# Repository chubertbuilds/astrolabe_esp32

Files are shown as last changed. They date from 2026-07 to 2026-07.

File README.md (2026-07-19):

<h1 align=center>
  Astrolabe
</h1>
<h3 align=center>
  An ESP32-S3 implementation of the historical scientific instrument
</h3>

<p align=center>
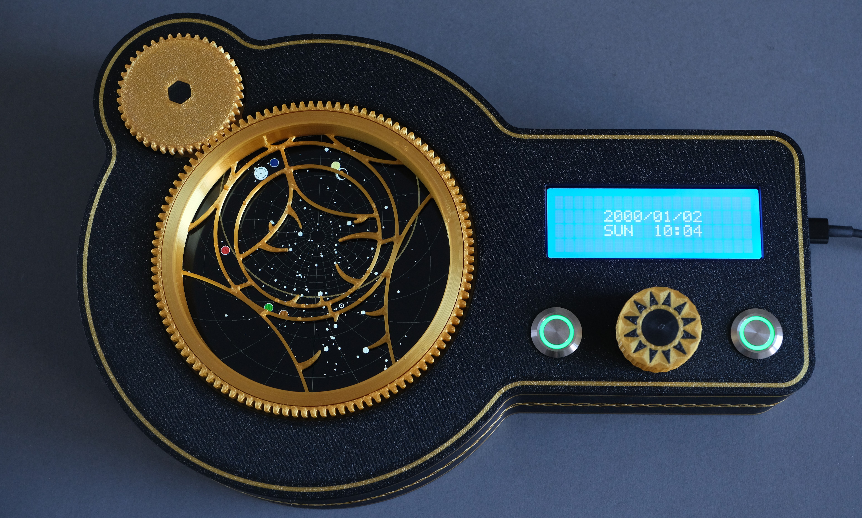
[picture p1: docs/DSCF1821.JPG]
  
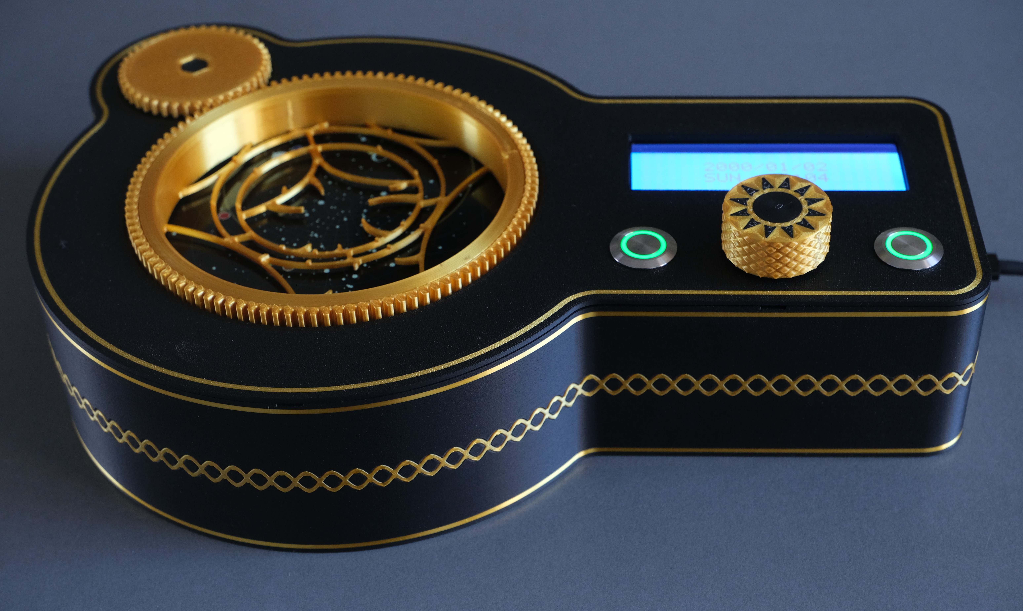
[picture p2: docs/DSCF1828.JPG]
   
</p>

## Licensing
The hardware and software designs in this repository are licensed separately:

* **Software:** The .ino sketch in the root folder and all files in "src" are licensed under the [MIT License](LICENSE).
* **Hardware:** The CAD files in "hardware" are all licensed under the [CERN-OHL-S License](LICENSE-HW).

## Introduction
An [astrolabe](https://en.wikipedia.org/wiki/Astrolabe) is a historical scientific instrument which was used to tell the time, map the sky, and find directions—among, it is obligatory to say, many other applications.

This project provides the hardware and software files to build a modern, microcontroller-driven version of the astrolabe. Given a user-inputted date, time, and location, it maps the fixed stars and seven classical planets on a 4''x4'' LCD panel. A secondary 20x4 character LCD screen displays detailed information about the sky.

Alex Boxer's [online astrolabe](https://alexboxer.com/astrolabe/) provided the inspiration for this project. If you're curious about these beautiful devices, I highly recommend you explore Boxer's astrolabe to learn more.

## Components

I used the following components in this build:

| Component  | Quantity
| --- | --- |
|[Qualia ESP32-S3 Dev Board](https://www.adafruit.com/product/5800)| 1
|[4'' 720 x 720 Display](https://www.adafruit.com/product/5793)| 1
|[i2c LCD Backpack](https://www.adafruit.com/product/292)| 1
|[20x4 Character Display](https://www.adafruit.com/product/198)| 1
|[Rotary Encoder Breakout w/ Encoder](https://www.adafruit.com/product/5880)| 1
|[PCF8574 I2C Breakout](https://www.adafruit.com/product/5545)| 1
|[16mm RGB Momentary Button](https://www.adafruit.com/product/3350)| 2
|[200mm JST SH 4-Pin Cables](https://www.adafruit.com/product/4401)| 3
|[40-pin FPC Extension](https://www.adafruit.com/product/2098)| 1
|3-pin JST PH Cable male connector w/ pigtails | 1 |
|Pair of 2-pin JST male-female connectors w/ pigtails | 1 |
| Pair of 6-pin JST male-female connectors w/ pigtails | 2|
| [10-turn 1K ohm Potentiometer](https://www.amazon.com/Taiss-Precision-Potentiometer-Adjustable-3590S-2-103L/dp/B07D7YH9N2/) | 1 |
| 110 ohm trimmer resistor | 1 |
| [#4 1/4'' Thread-Forming Phillips Screws](https://www.mcmaster.com/90417A116/) | 50
| [5/16'' Ø Delrin Balls](https://www.mcmaster.com/products/9614k57/) | 12
| [0.06'' Ø 1/8'' Thick Neodymium Magnets](https://www.mcmaster.com/catalog/5862K11) | 16
| [4-40 1/4'' Set Screws](https://www.mcmaster.com/products/92311a106/) | 4
| 110 Ohm, 0.25 W Resistor | 1

Where possible, I'm linking to the exact component I purchased. Substitutions can be made as needed.

## 3D Printing

The twelve 3D-printed parts used in this project are all listed in the [hardware](hardware) folder. All of these parts must be printed once, except for Astrolabe_BearingCage, which must be printed twice.

I printed all these parts with a Bambu P1S printer, using a combination of matte black and silk gold PLA filament. Given that my setup will likely differ substantially from yours, I haven't provided .3mf files (also, to tell the truth, I didn't do a great job of record-keeping with my print files).

Some 3D printing pointers:

- Some parts need to be printed with their counterbores upside down. For these parts, there are features on the counterbores which force the slicer to use bridges, eliminating the need for supports.
- While some parts can be printed in orientations that eliminate supports, those orientations may not be ideal. For example, the encoder knob can be printed with the knob face on the print bed; this orientation doesn't need supports, but it makes the knob less shiny.
- When printing with silk gold PLA, I recommend lowering speeds to <50 mm/s for the outer walls and the top layer.
- When printing with supports, I recommend using a PLA-incompatible material, such as PETG or the proprietary Bambu "Support for PLA/PETG," for the support interface.

Finally, several parts interface with tight clearance fits. Depending on your setup, you may need to modify dimensions to get a good fit. If you need to do so, or you want to make any other change to the design, you can access .STEP files [here.](hardware/step/)

## Build Instructions

### Tools
This build uses the following tools and consumables:

- A #1 phillips head screwdriver
- A 0.05'' Allen wrench
- A soldering station
- Epoxy glue 
- Nylon tape
- A 4-40 tap

### Soldering
Before beginning assembly, all the soldering work should be complete. The soldering work is comprised of the following tasks:

  1. Solder the character display backpack to the character display. Note: the screw terminal on the backpack needs to be removed, as it doesn't fit in the build. This can be done via a skillful, dextrous desoldering job, or you can use a pair of pliers to rip the screw terminal off the PCB. Guess which path I took.
  2. Solder the 3-pin JST PH cable to the prongs of the potentiometer. On the Qualia's 3-pin JST connector, the left pin is signal, the middle pin is power, and the right pin is ground. Connect signal to potentiometer pin 2, power to potentiometer pin 1, and ground to potentiometer pin 3.
  3. Cut the power wire and splice the 110 Ohm resistor into it. The ESP32-S3 onboard ADC has a completely flat response at the top of its voltage input range, so we need the resistor to adjust the input signal.
  4. Solder one half of the 2-pin JST connector pair to the Qualia board. Solder one wire to MOSI and the other to MISO. We are repurposing these extra GPIO pins for interrupt signals.
  5. Solder the other half of the 2-pin connector pair to the interrupt pins of the encoder breakout and the GPIO expander. Connect MOSI to the encoder interrupt pin and MISO to the expander interrupt pin.
  6. For both buttons, solder one half of a 6-pin JST connector to the button. Each button comes with six prongs: an anode, two button contacts, and three LED cathodes.
  7. Solder the other half of the two 6-pin connectors to the GPIO expander. For the button-expander connections, solder the anode to power, the three LED cathodes to GPIO pins, one of the button contacts to ground, and the other button contact to a GPIO pin. All eight of the GPIO expander's pins should be occupied. The existing code uses the following pin assignments: 

      ~~~
      #define RIGHT_BLUE 0 
      #define RIGHT_GREEN 1 
      #define RIGHT_RED 2 
      #define RIGHT_BUTTON 3 
      #define LEFT_BLUE 4 
      #define LEFT_GREEN 5 
      #define LEFT_RED 6 
      #define LEFT_BUTTON 7 
      ~~~

### Bearing Cage Magnet Insertion

Before assembly, we also need to insert and glue magnets into the two bearing cage halves.

It's important to keep all the magnetic poles aligned—one of the cage halves must have all its magnets mounted with the north pole facing out, and one of them must have all the magnets with the south pole facing out.

To cleanly insert and glue the magnets:

1. Create a reservoir of epoxy.
2. Use a flathead screwdriver to pick up the magnet. The side that will face out should be contacting the tool.
3. Dip the other end of the magnet in the epoxy reservoir.
4. Use the screwdriver to press the magnet into the cage bore. 
5. Once the magnet has been fully inserted, slide the screwdriver off to break contact with the magnet. This breaks contact without pulling the magnet back out of the bore.
6. Let the cage sit for your epoxy's cure time.

### Tapping the Axle

The potentiometer axle uses four set screws to couple it to the potentiometer shaft. To insert these set screws into the axle, the four through holes in the axle must be tapped with a 4-40 tap.

To be sure, it is absolutely not best practice to directly tap a 3D-printed part, given that the resulting threads are quite weak. That said, they are strong enough for our application.

### Assembly

After printing, soldering, gluing, and tapping, it's time to build!

1. Gather all the 3D-printed parts and components on a large, clear workspace.

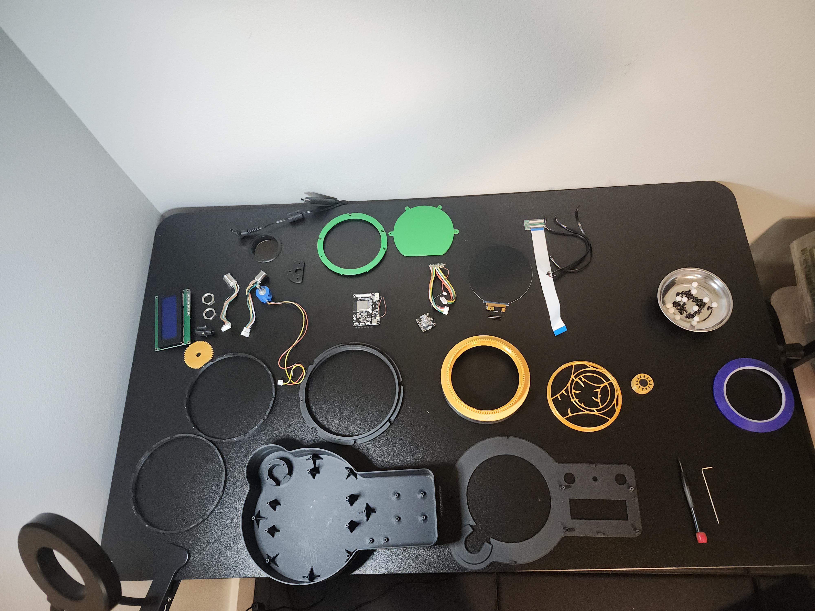
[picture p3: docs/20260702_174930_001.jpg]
    

2. Assemble the bearing. 
    - Arrange the inner bearing inside the outer bearing eccentrically, such that the outside of the inner bearing is making contact with the inside of the outer bearing at one point.
    - This will create a large gap on the opposite side of the contact point, through which the nylon balls can be inserted. Insert all twelve.

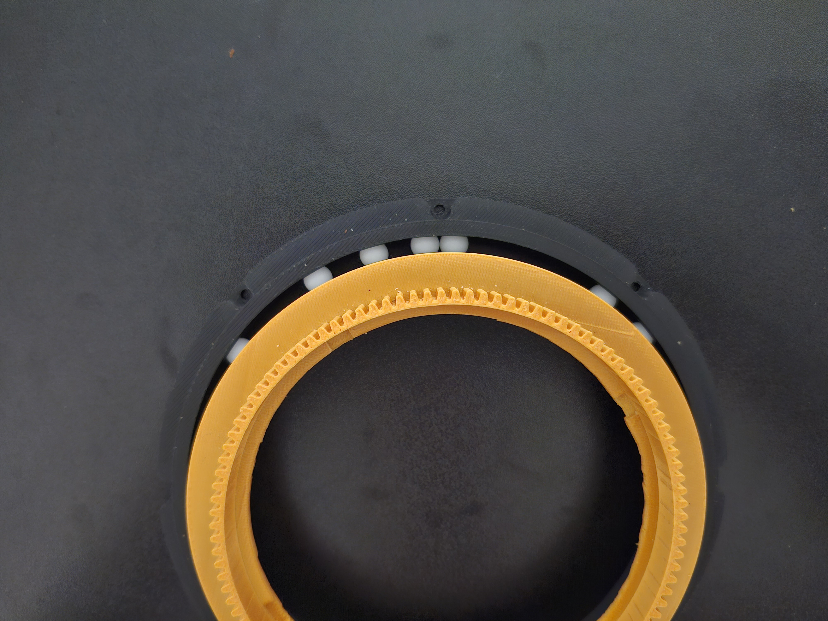
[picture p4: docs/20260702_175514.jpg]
        

    - As the balls are inserted, arrange them in a roughly even spacing. This will cause the inner and outer bearing to become concentric.
    - Take one half of the bearing cage and place it under the balls. The balls will not be inside their pockets, so the cage will not be fully seated.
    - Using a long tool such as a screwdriver, push the balls along the track until each ball is over a pocket. Once this happens, the assembly will fall into place over the bearing cage.

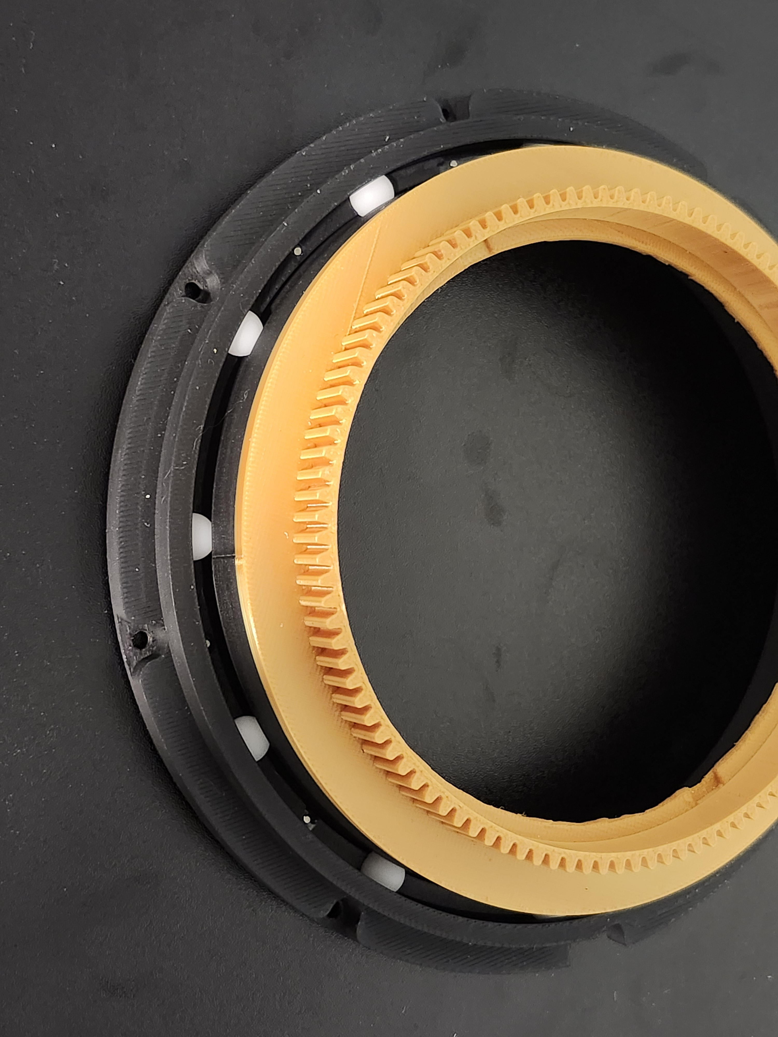
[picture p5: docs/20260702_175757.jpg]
        

    - Place the other half of the bearing cage over the assembly; the magnets will lock it into place.

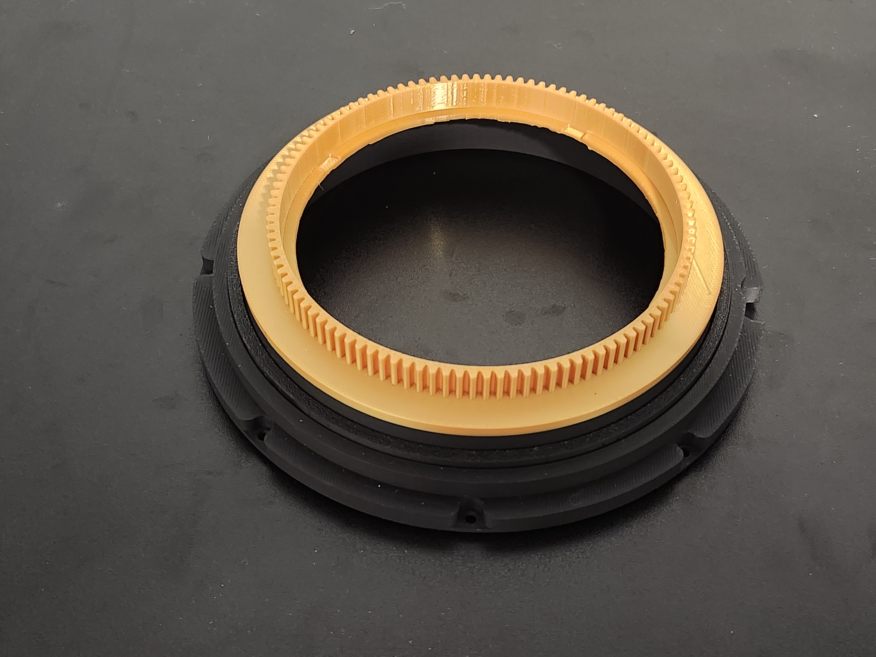
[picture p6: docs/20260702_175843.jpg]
        

    - Spin the bearing around like a fidget toy.
3. Assemble the display enclosure.
    - Insert the display inside the display mount, facing out.

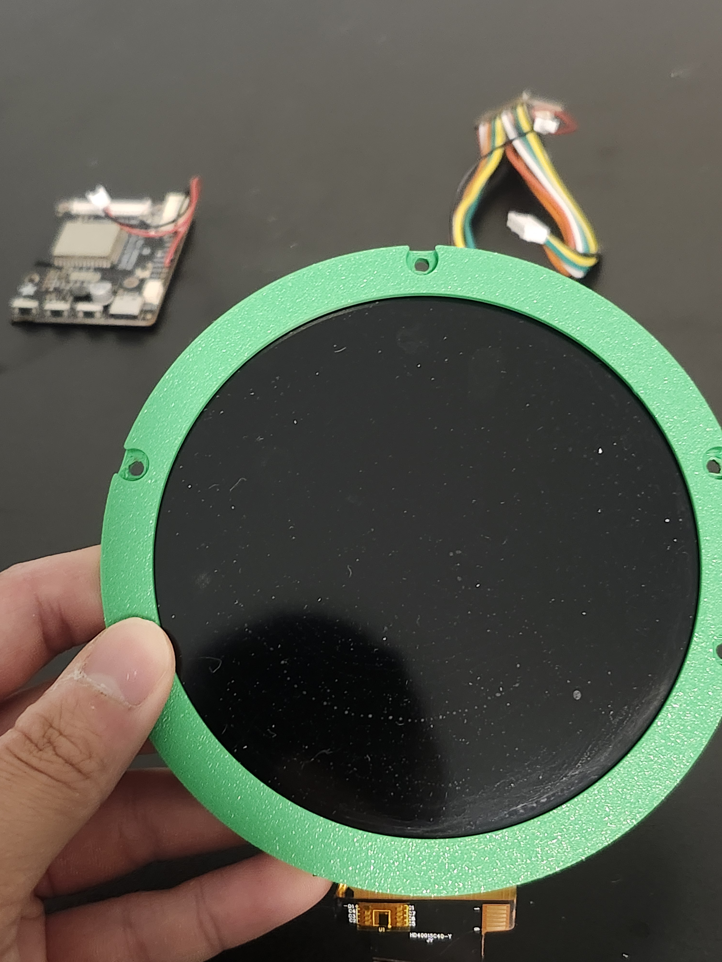
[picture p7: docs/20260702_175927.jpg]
        

    - Fit the display base on the other side of the display mount, sandwiching the display between the two parts.

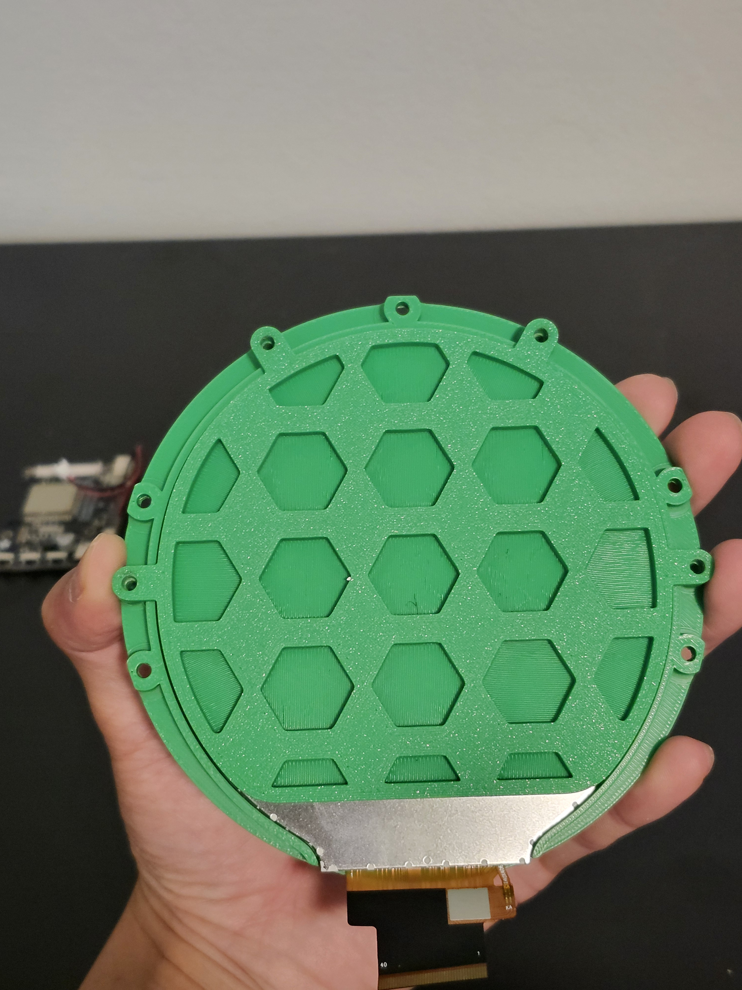
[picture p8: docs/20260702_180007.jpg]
        

    - Fasten the display mount and base together with four screws.
4. Insert the potentiometer into the housing base.
5. Capture the potentiometer with the potentiometer cap and three screws.

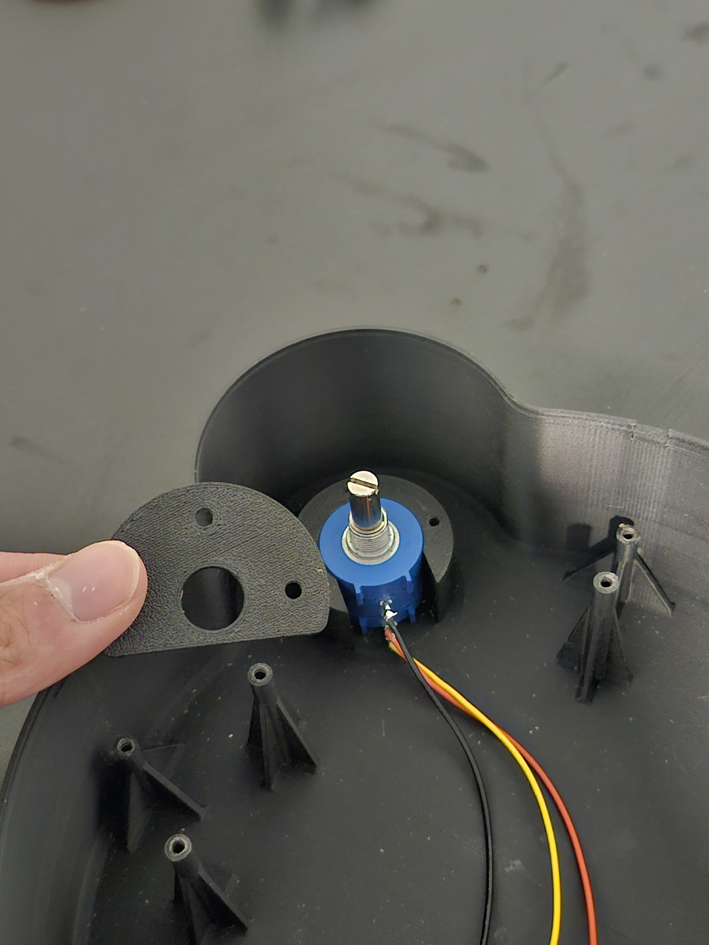
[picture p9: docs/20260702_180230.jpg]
    

6. Connect one JST SH 4-pin cable (hereafter referred to as an I2C cable) to the I2C port on the Qualia dev board.
7. Connect the potentiometer connector to the 3-pin JST port on the Qualia dev board.
8. Fasten the Qualia to the four bosses on the bottom of the housing base.

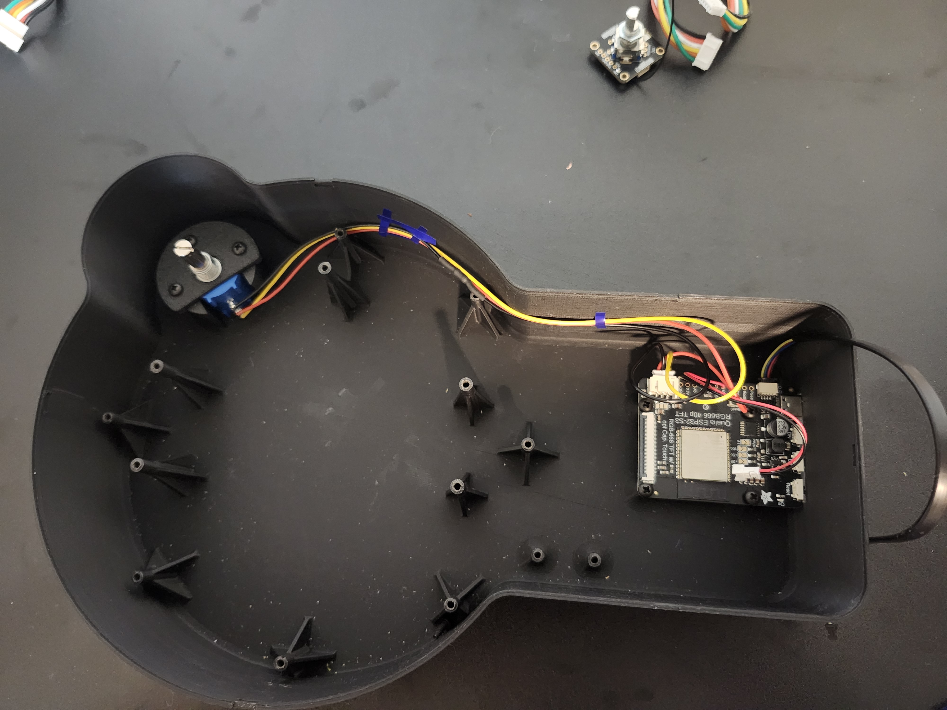
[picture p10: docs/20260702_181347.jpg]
    

9. Insert one end of the 40-pin FPC extension cable into the FPC extension board, and the other end into the Qualia. The metal pins **must be facing downward, as shown in the photograph.** It is possible to insert the cable backwards and engage the locking mechanism, which will invert the connections and damage your display.

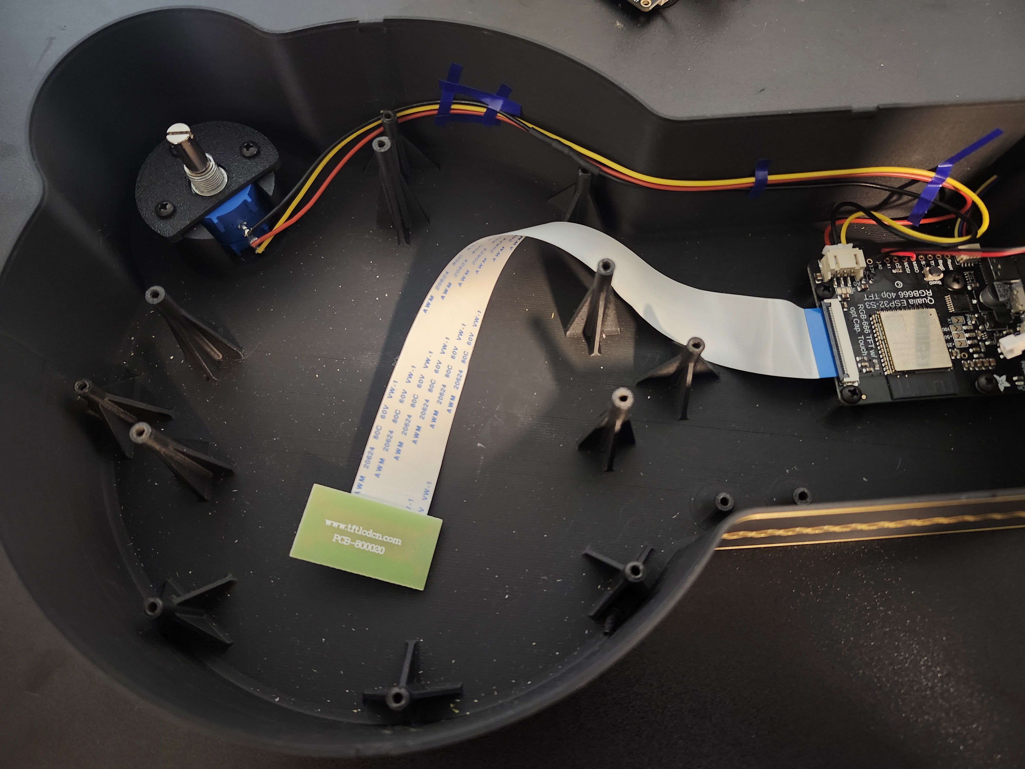
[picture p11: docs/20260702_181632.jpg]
    

10. Fold and tape the extension cable as shown in the photograph. This prevents the cable from interfering with the bearing's rotary action.

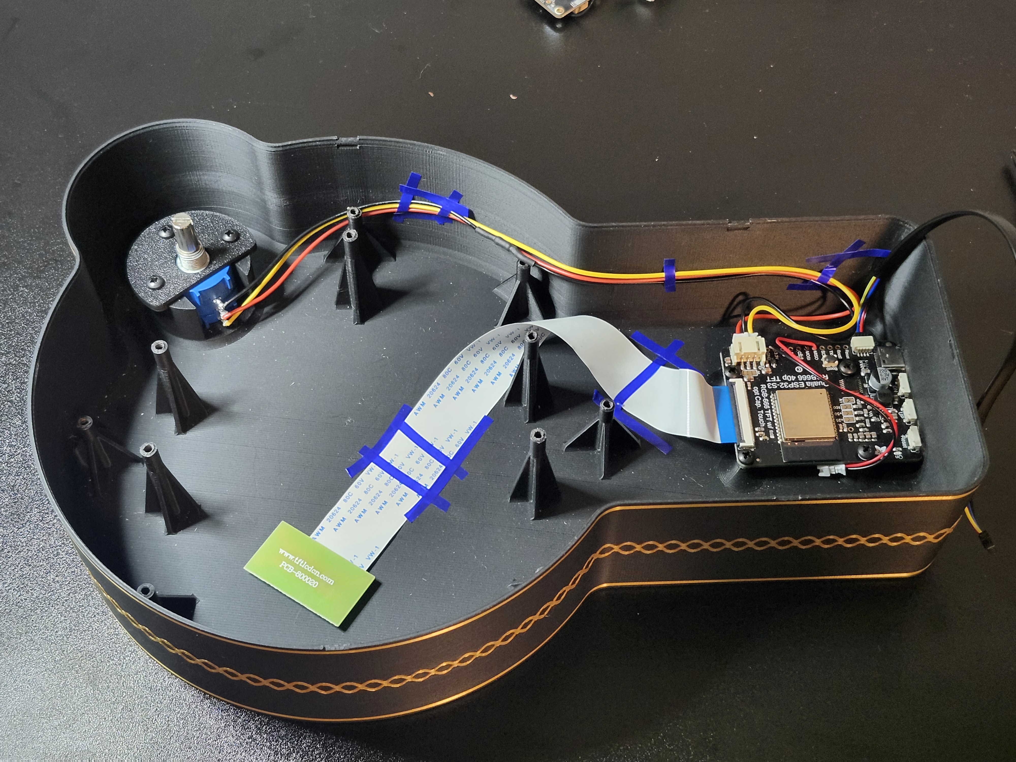
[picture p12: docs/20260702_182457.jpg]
    

11. Connect the FPC cable to the display.

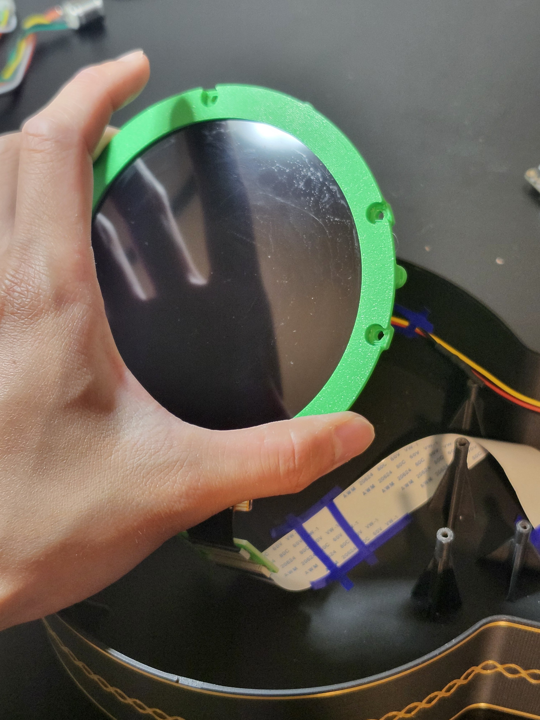
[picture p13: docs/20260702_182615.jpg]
    

12. Fasten the display enclosure to the five inner bosses.

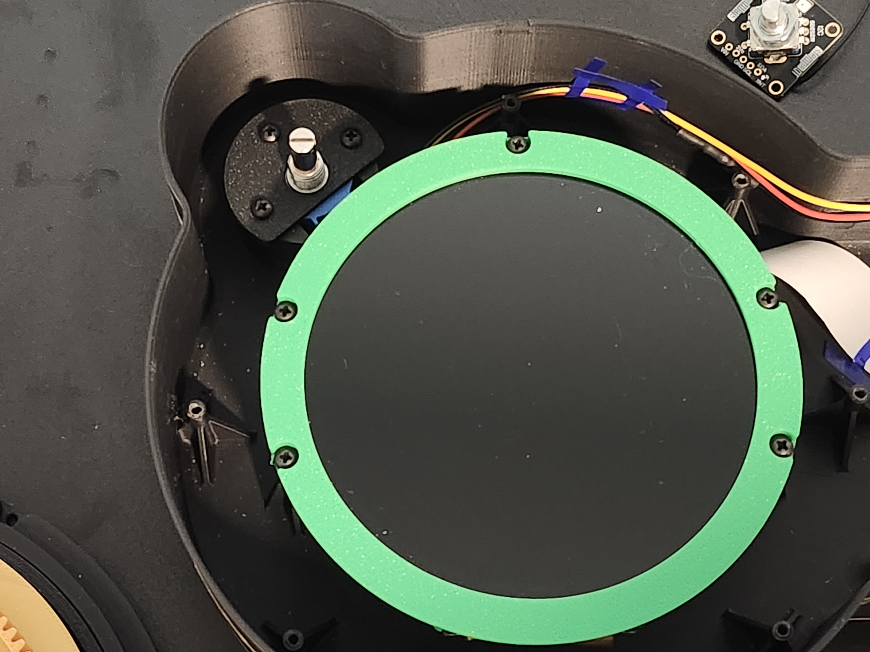
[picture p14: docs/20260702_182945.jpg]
    

13. Lower the bearing over the display enclosure and fasten it to the seven outer bosses.

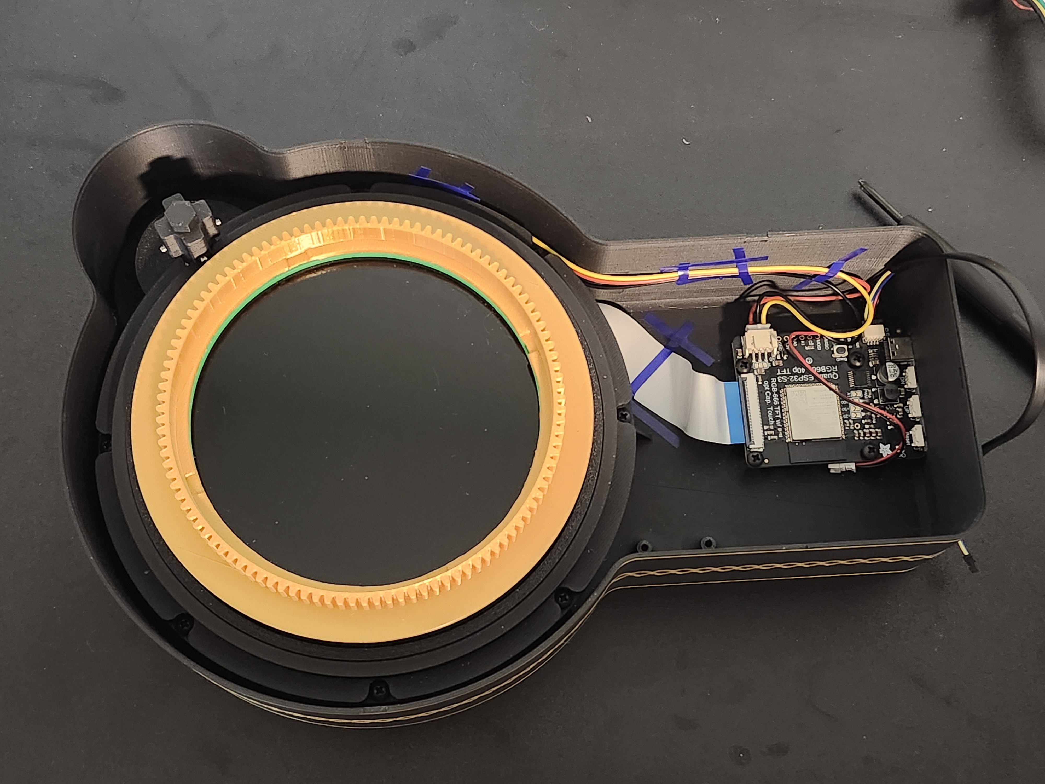
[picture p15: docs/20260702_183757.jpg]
    

14. Slide the potentiometer axle over the potentiometer shaft and tighten it with the hex key.

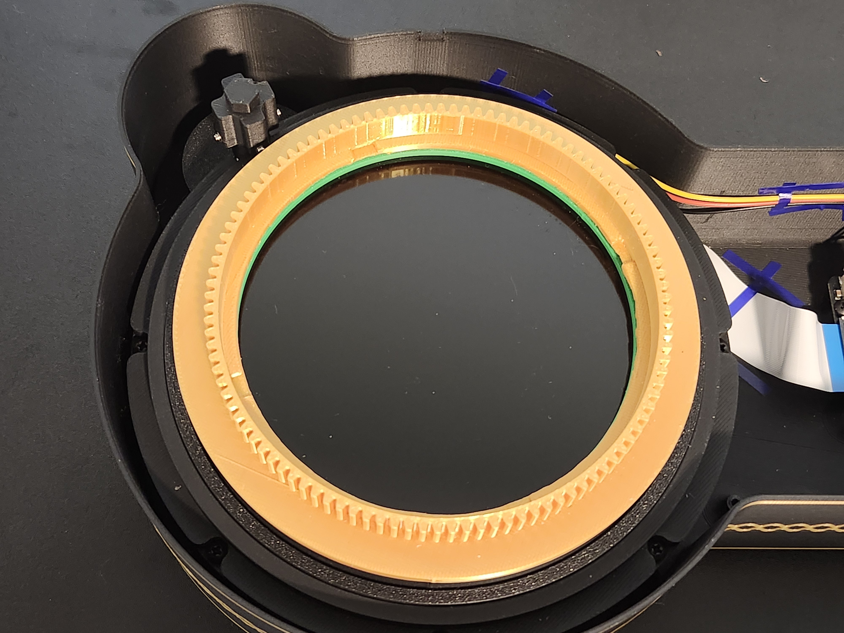
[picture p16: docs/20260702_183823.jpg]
    

15. Connect the GPIO expander to the Qualia dev board with the I2C cable.

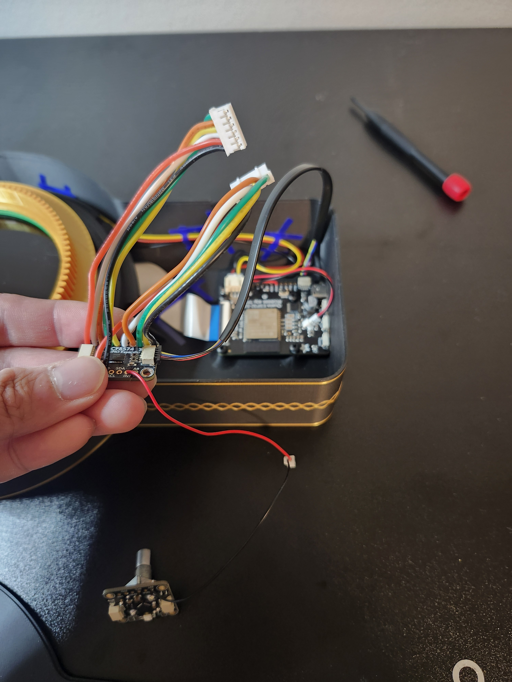
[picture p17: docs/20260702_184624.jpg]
    

16. Use the included nuts to fasten the two buttons and the encoder to the housing lid.

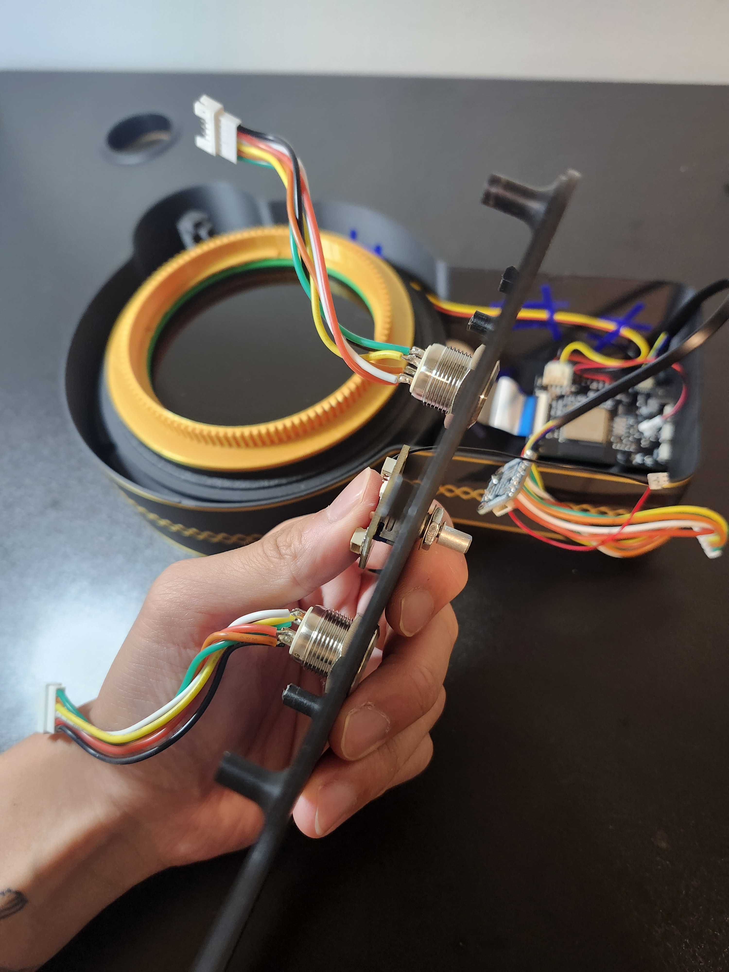
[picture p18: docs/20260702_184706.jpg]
    

17. Connect the GPIO expander and the encoder breakout with an I2C cable.

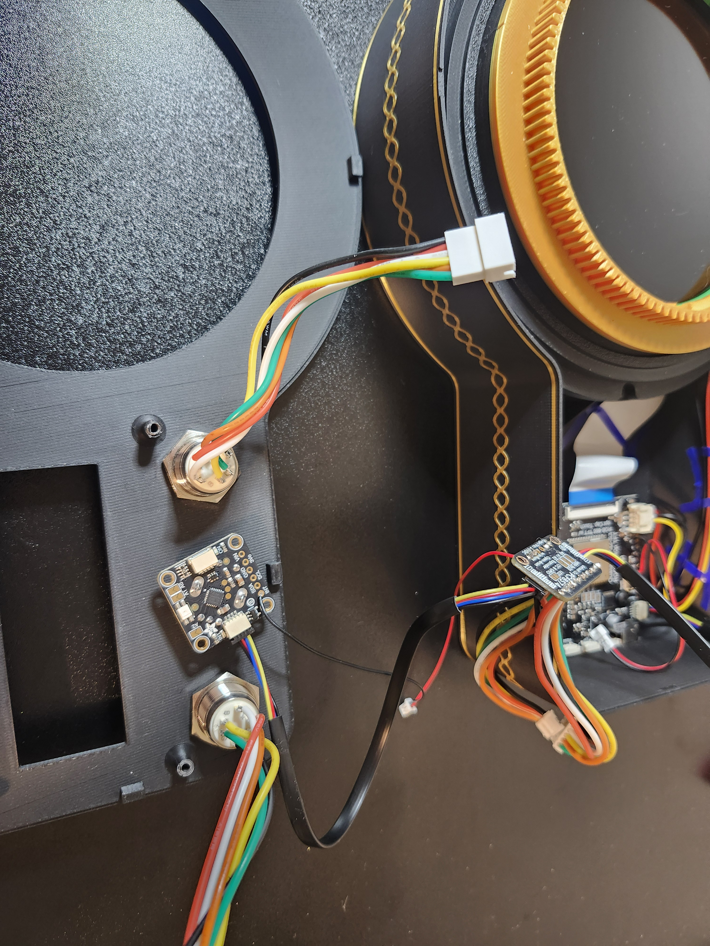
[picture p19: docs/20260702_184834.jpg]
    

18. Fasten the character LCD to the lid with three screws.
19. Connect the encoder breakout and the character LCD with an I2C cable.

    

20. Fasten the GPIO expander to the two remaining bosses on the bottom of the housing base.
21. Connect the two 6-pin JST connectors.

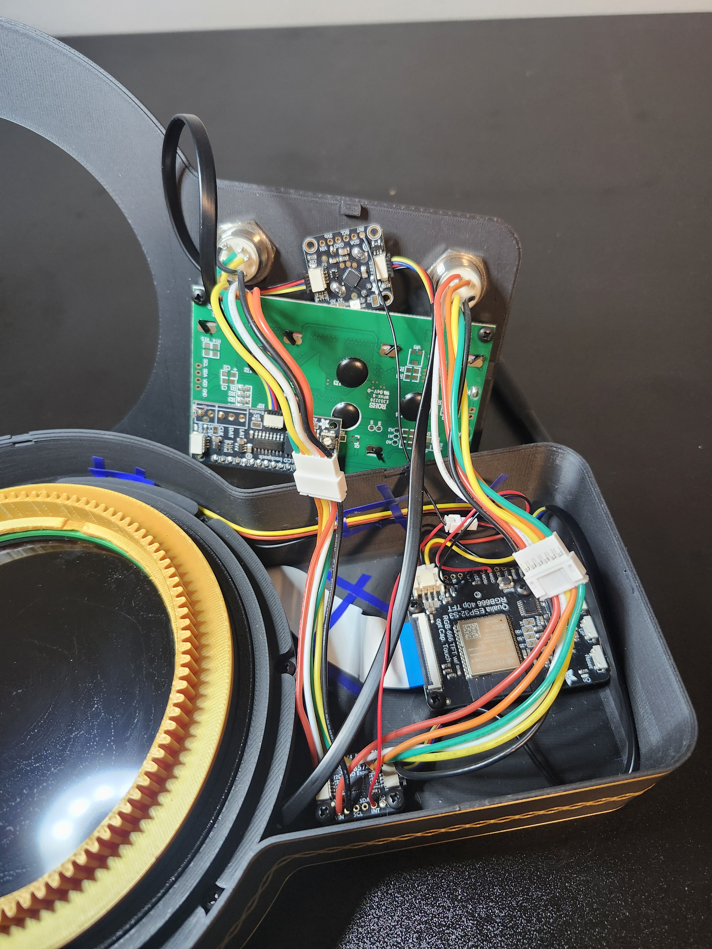
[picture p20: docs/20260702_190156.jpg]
    

22. With everything connected, fit the housing lid over the housing base. It snaps into place.

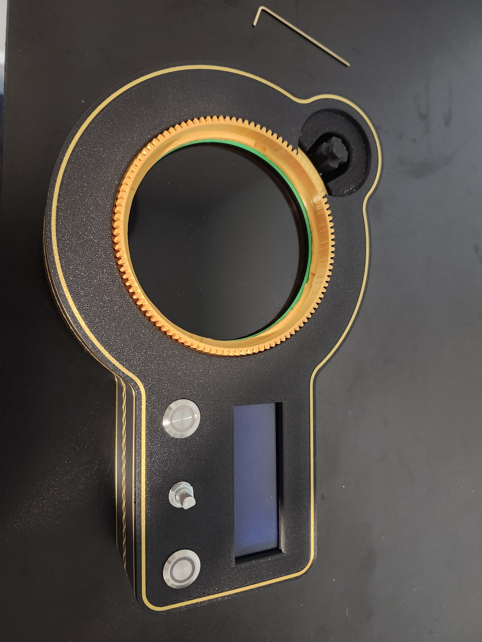
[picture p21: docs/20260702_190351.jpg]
    

23. At this point, the build is basically complete—congratulations! To finalize the build, the firmware needs to be uploaded. Follow the instructions in [firmware setup](#firmware-setup).
24. Once the astrolabe gets its firmware flashed, you will see the star map displayed on the main LCD panel. Insert the rete into the slots on the inner bearing, and then rotate the bearing until the rete is aligned with the star map. 

    

25. Press the secondary potentiometer gear over the hex boss, coupling the movement of the rete to animation on the display.

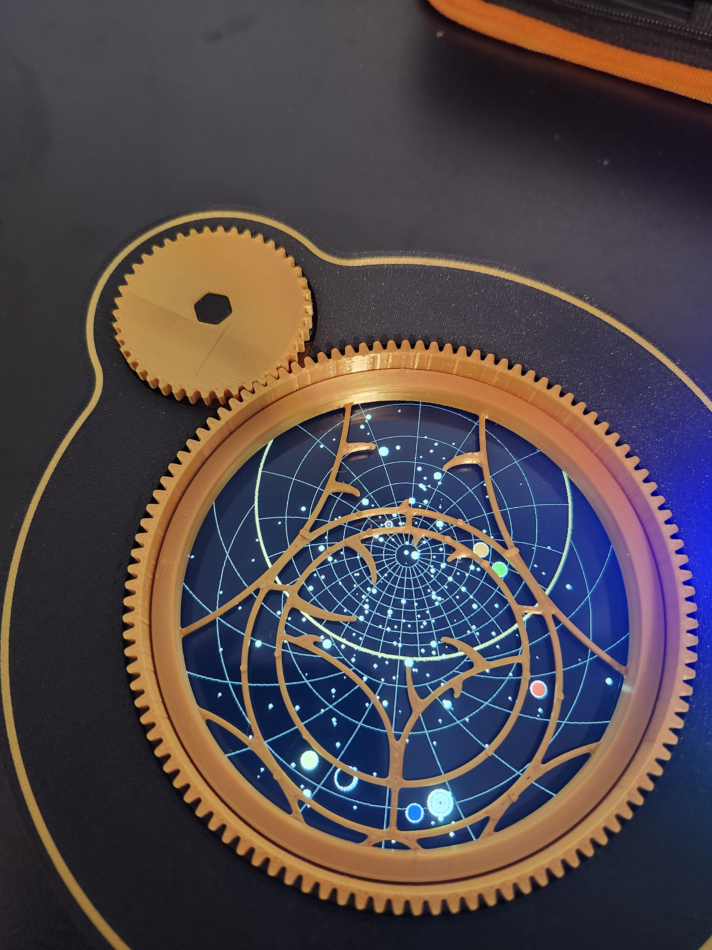
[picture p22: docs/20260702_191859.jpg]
    

## Firmware Setup

We'll use the Arduino IDE to flash the firmware onto the astrolabe.

The Qualia dev board uses an ESP32-S3, and the Qualia itself is a supported board in the Arduino IDE. To start, we need to set up the Arduino IDE with the Qualia dev board. Follow [Adafruit's instructions](https://learn.adafruit.com/adafruit-qualia-esp32-s3-for-rgb666-displays/arduino-ide-setup) to do so.

You'll also need to download several Arduino libraries to use this firmware; these libraries are mostly used to drive the various peripheral chips in this project. These external libraries are:

1. Adafruit XCA9554
2. Adafruit LiquidCrystal
3. Adafruit PCF8574
4. Adafruit Seesaw Library
5. CircularBuffer

Once these libraries are all installed, you should be able to compile the main .ino sketch file and flash it onto your device. I use the following settings, taken from [jfseaman's Qualia examples repo](https://github.com/jfseaman/Qualia_ESP32S3_RGB666):

| Arduino IDE Setting | Value |
| --- | --- |
| Board | **Adafruit Qualia ESP32-S3 RGB666**  |
| Port | Your port |
| USB CDC On Boot | Enable |
| CPU Frequency | 240MHZ(WiFi) |
| Core Debug Level | None |
| USB DFU On Boot | Disable |
| Erase All Flash Before Sketch Upload | Disable |
| Events Run On | Core1 |
| Flash Mode | QIO 80MHZ |
| Flash Size | **16MB(128Mb)** |
| Arduino Runs On | Core1 |
| USB Firmware MSC On Boot | Disable |
| Partition Scheme | **Default(6.25MB APP/3.43MB FATFS)** |
| PSRAM | **OPI PSRAM** |
| Upload Mode | **UART0/Hardware CDC** |
| Upload Speed | 921600 |
| USB Mode | **CDC and JTAG** |

## User Settings

The .ino sketch contains the following lines of code:

~~~
bool DST = false; //insert your own default DST setting
int UTC_offset = 0; //insert your own default timezone

...

float latitude = 0.1; //insert your own default latitude
float longitude = 0.0; //insert your own default longitude
~~~

Modifying these values will modify your astrolabe's default settings.

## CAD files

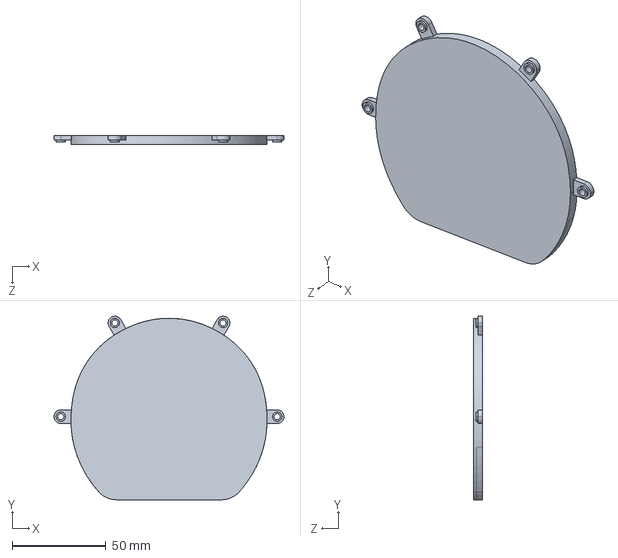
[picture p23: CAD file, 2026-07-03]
hardware/step/Astrolabe_DisplayBase.STEP
122.8 x 98.1 x 4.62 mm

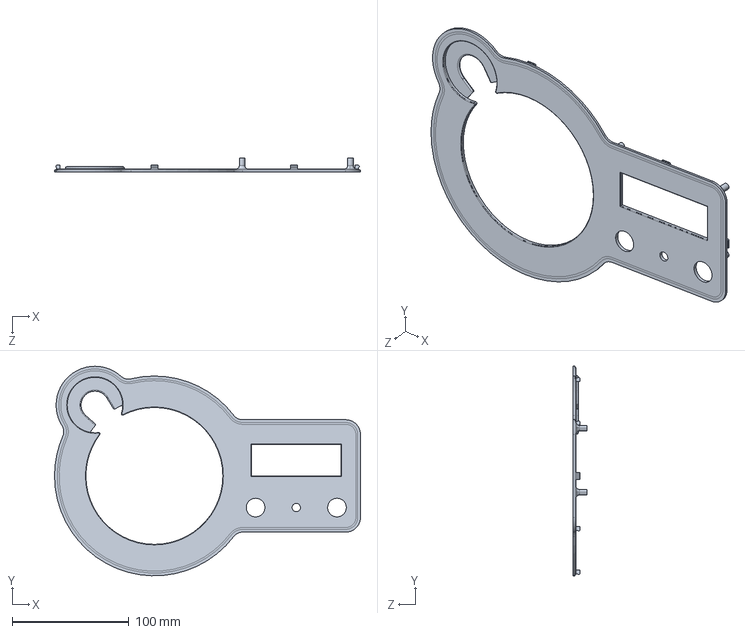
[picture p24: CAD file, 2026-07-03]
hardware/step/Astrolabe_HousingLid.STEP
262.6 x 179.8 x 11.8 mm

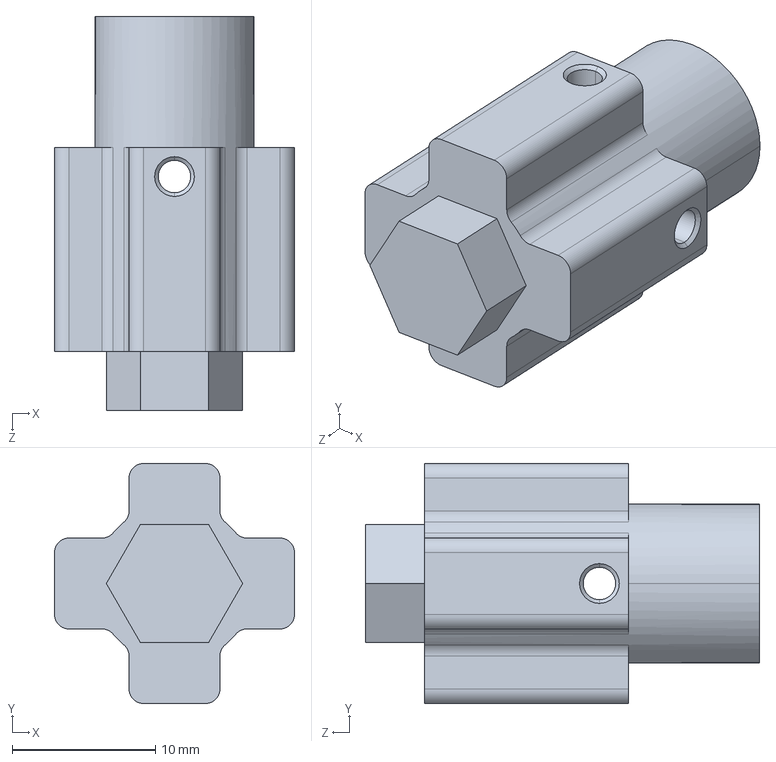
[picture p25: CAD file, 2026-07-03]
hardware/step/Astrolabe_PotAxle.STEP
16.8 x 16.8 x 27.5 mm

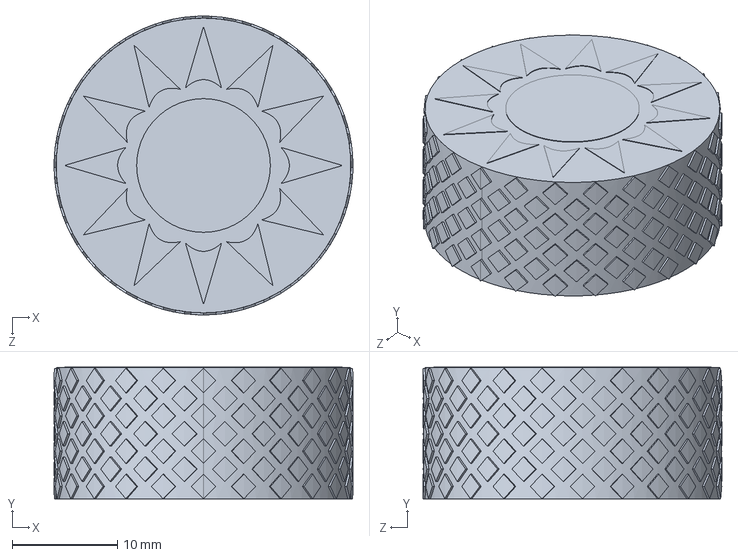
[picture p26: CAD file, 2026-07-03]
hardware/step/Astrolabe_EncoderKnob.STEP
28.4 x 12.5 x 28.4 mm

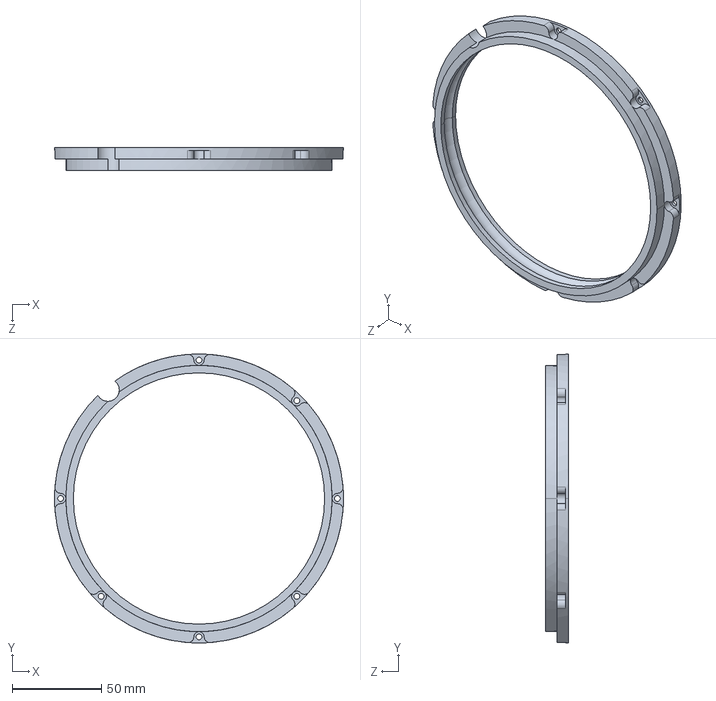
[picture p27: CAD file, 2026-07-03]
hardware/step/Astrolabe_BearingOuter.STEP
161.9 x 161.9 x 12.7 mm

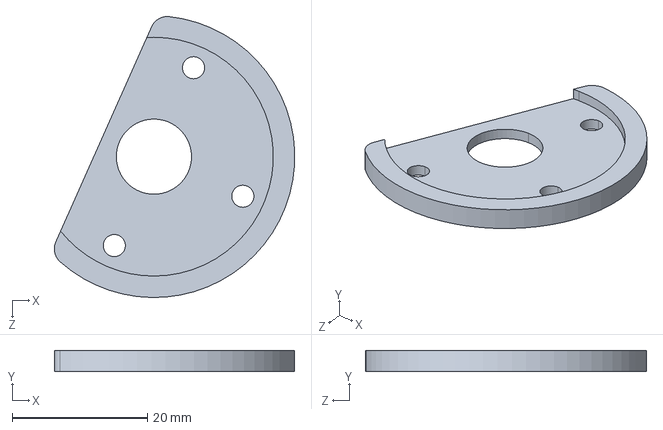
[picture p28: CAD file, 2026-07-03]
hardware/step/Astrolabe_PotCap.STEP
35.5 x 3.17 x 41.5 mm

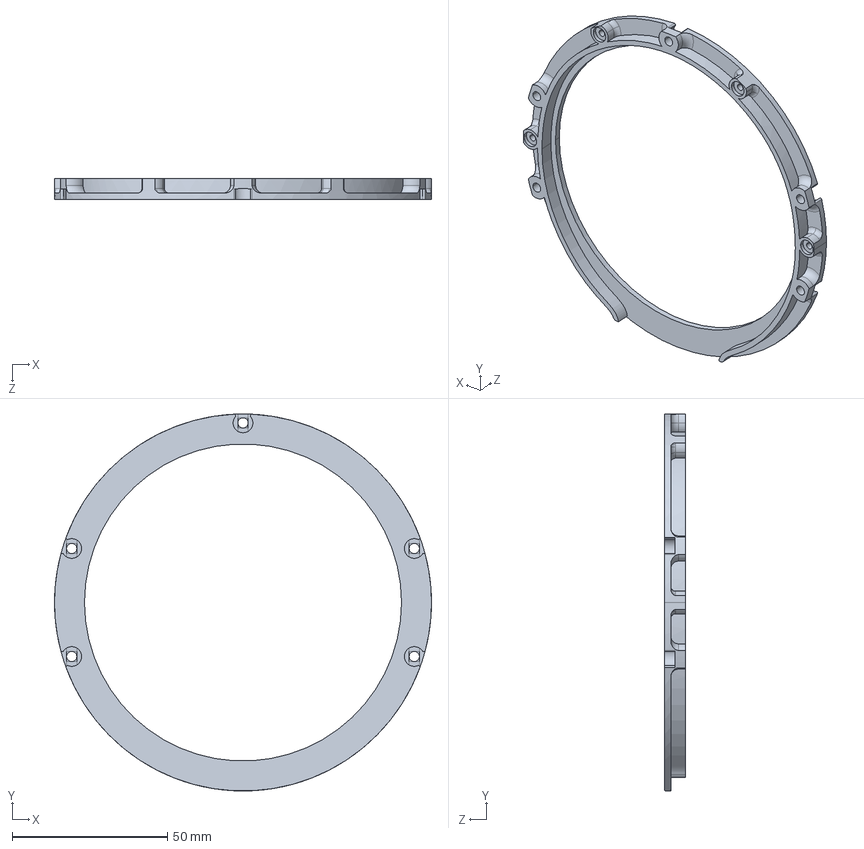
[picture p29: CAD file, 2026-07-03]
hardware/step/Astrolabe_DisplayMount.STEP
121.3 x 121.3 x 6.79 mm

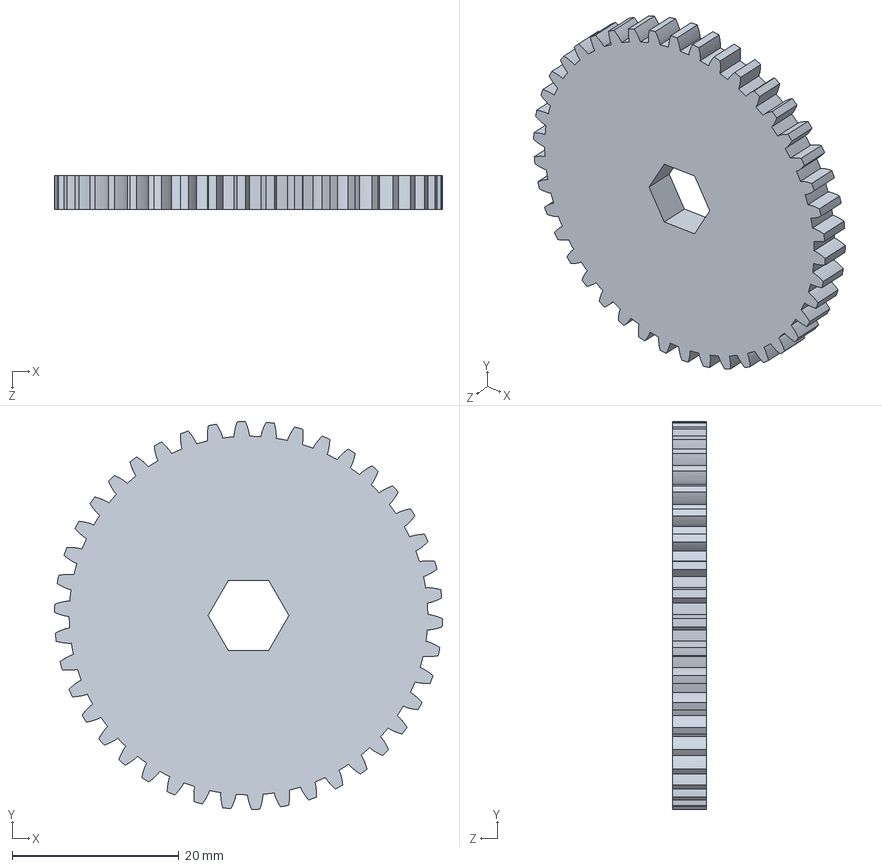
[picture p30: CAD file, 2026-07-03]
hardware/step/Astrolabe_PotGear.STEP
46.6 x 46.6 x 4.13 mm

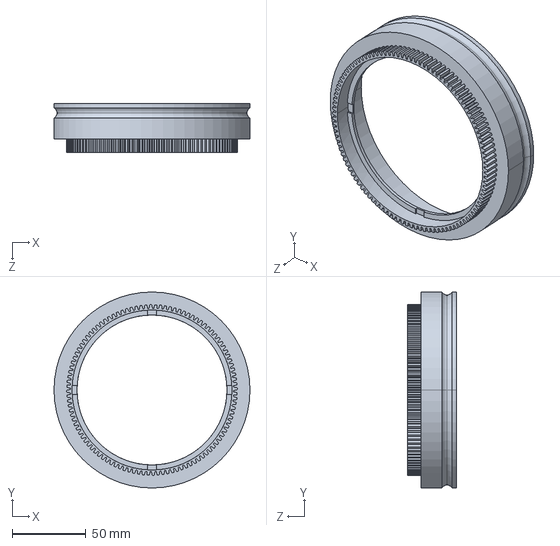
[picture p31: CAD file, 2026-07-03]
hardware/step/Astrolabe_BearingInner.STEP
132.8 x 132.8 x 33.0 mm

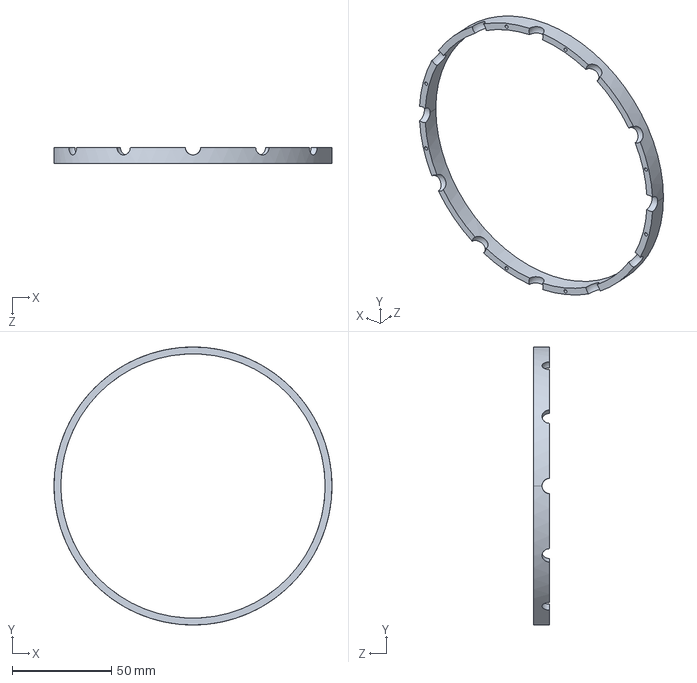
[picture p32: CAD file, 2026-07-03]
hardware/step/Astrolabe_BearingCage.STEP
140.3 x 140.3 x 8.26 mm

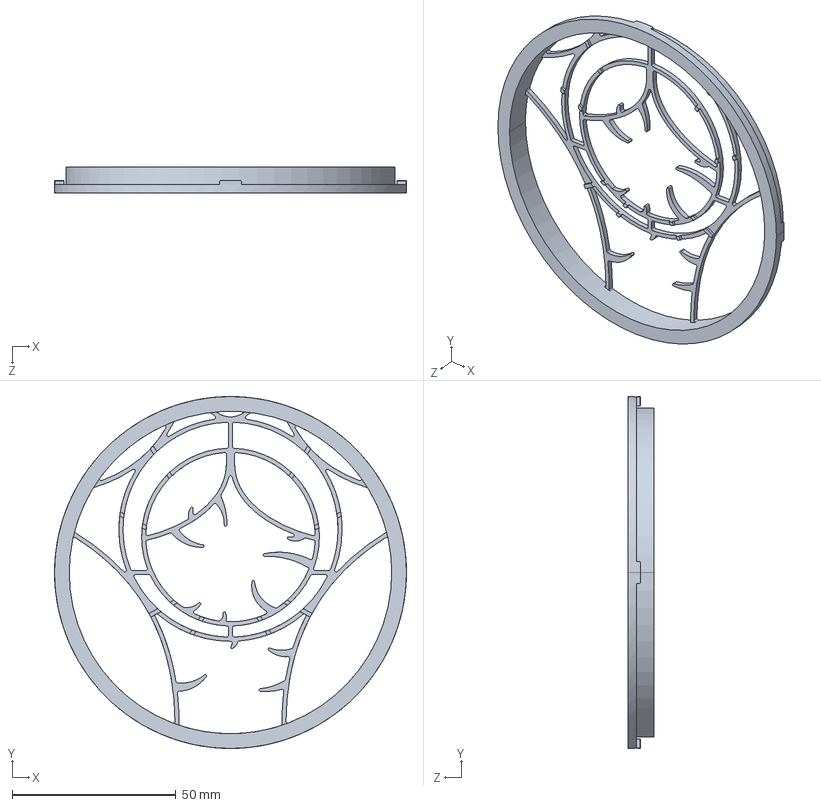
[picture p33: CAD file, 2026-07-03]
hardware/step/Astrolabe_StereographicRete.STEP
107.4 x 107.4 x 7.87 mm

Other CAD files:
hardware/stl/Astrolabe_DisplayBase.STL
hardware/stl/Astrolabe_EncoderKnob.STL
hardware/stl/Astrolabe_PotAxle.STL
hardware/stl/Astrolabe_PotCap.STL
hardware/stl/Astrolabe_PotGear.STL
hardware/stl/Astrolabe_StereographicRete.STL

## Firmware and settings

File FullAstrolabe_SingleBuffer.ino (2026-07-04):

#include "src/PCA9554_Qualia.h"
#include "src/PanelConfig.h"
#include "src/PotentiometerCalibrator.h"
#include "src/CalibrationPoints.h"
#include "src/StarChart.h"
#include "src/Tympanum.h"
#include "src/CircleMath.h"
#include "src/AstrolabeInterface.h"

#include "CircularBuffer.hpp"
#include "esp_lcd_panel_rgb.h"
#include "esp_lcd_panel_ops.h"
#include <array>
#include "esp_heap_caps.h"

#define SATURN_COLOR 0x9ac3
#define MARS_COLOR 0xc104
#define VENUS_COLOR 0Xffd2
#define MERCURY_COLOR 0x18ad
#define JUPITER_COLOR 0x0505
#define SUN_COLOR 0xffff
#define MOON_COLOR 0xffff
#define BG_COLOR 0x0000
#define STAR_COLOR 0xe73c
#define LINE_COLOR 0x4228
#define HIGHLIGHT_COLOR 0x7b48
#define OUTLINE_COLOR 0xffff

#define SATURN 4
#define MARS 2
#define VENUS 1
#define MERCURY 0
#define JUPITER 3
#define SUN 6
#define MOON 5
#define ANTISOLAR 7

#define SUN_SIZE 18
#define MOON_SIZE 16
#define PLANET_SIZE 12
#define ANTISOLAR_SIZE 6

// Create an instance of the Adafruit_XCA9554 class
PCA9554_Qualia expander;

//global framebuffers
void* framebuffer = nullptr;
uint16_t* fb;
uint16_t* fb_bg;

int post_change_frames = 4;  //draw n frames after angle stops changing
uint8_t frame_change_counter = 0;
uint8_t loop_entry_counter = 5;  //get around frame change counter on first n loops

//star map drawing variables
float angle = 0;
float old_angle = 0;
float old_eph_angle = 0;
float erase_angle = 0;
int old_center_x, old_center_y, center_x, center_y;
int i, j;
int n_stars;
const float k_star_size = 0.23;
const float scale_factor = 193.75;  //3.875'' map = 3.6 in stereographic projection units, 180 pixels/in  3.875/3.6*180
float star_r, star_size, star_long;
bool angle_changed;


//planet drawing variables
PlanetData data, old_data;
const int n_planets = 8;
float planet_r, planet_long;
uint16_t planet_color;
StereoCoords planet_coords;
float planet_size;
int sun_center_x, sun_center_y;
float sun_long = 0;
float phase_angle;
std::array<std::array<int, 2>, n_planets> planet_erase_locs;
RetrogradeInfo ri;
std::array<SphereVector, 7> planets_altaz;
std::array<SphereVector, 12> stars_altaz;


//sun and moon drawing variables
const int sun_inner_r = 2;
const int sun_ring_r = 14;
const int sun_ring_thickness = 1;
const int moon_ring_thickness = 1;
const int moon_ring_spacing = 1;
const int planet_thickness = 1;
const int antisolar_inner_r = 1;

//potentiometer measurement
float sum_pot = 0;
float average_pot;
const int n_sample = 60;
PotentiometerCalibrator* calibrator;
const float calibration_k = 1.000;
std::vector<std::array<float, 2>> points;


//potentiometer buffering
const int n_buffer = 25;
const int buffer_size = n_buffer * n_sample;
CircularBuffer<int, buffer_size> buffer;

//time calculations
TimeCalculator* time_calculator;
int sidereal_day_offset = 0;
double jd, old_jd_back, old_jd_front;
DateTime dt;
bool DST = false; //insert your own default DST setting
int UTC_offset = 0; //insert your own default timezone

//tympanum
Tympanum* tympanum;
const int horizon_thickness = 4;
const int default_thickness = 1;
std::array<float, n_houses>cusps;
float latitude = 10.0; //insert your own default latitude
float longitude = 0.0; //insert your own default longitude

//display
AstrolabeInterface* interface;
InterfaceParams p;


esp_lcd_panel_handle_t panel_handle = NULL;

uint16_t color;

unsigned long timer;

long timer_cusp_calc;
long timer_eph;
long timer_eph_sample;
long timer_interface_update;
long timer_draw;

volatile bool encoder_irq;
volatile bool button_irq;
EncoderReturn encoder_return;
bool date_changed;
bool date_change_eph_request;
bool angle_changed_eph_old;

Adafruit_PCF8574 pcf;

std::array<Circle2D, n_almucantar> almucantar;
std::array<Circle2D, n_azimuth> azimuth;
std::array<Circle2D, n_hours> hours;
std::array<Circle2D, 3> tropics;
Circle2D horizon_unscaled;

Circle2D horizon;
Circle2D horizon_outside;

Settings new_settings;

void encoderIRQ() {
  encoder_irq = true;
}

void buttonIRQ() {
  button_irq = true;
}

void drawVerticalLine(int x, uint16_t color, int thickness, uint16_t* fb) {
  int left_bound = x - thickness < 0 ? 0 : x - thickness;
  int right_bound = x + thickness > 720 ? 720 : x + thickness;
  for (int i = 0; i <= 720; i++) {
    for (int j = left_bound; j <= right_bound; j++) {
      fb[i * 720 + j] = color;
    }
  }
}

void drawCircle(int x, int y, int r, uint16_t color, uint16_t* fb, bool erase = false) {
  int left_bound = x - r < 0 ? 0 : x - r;
  int right_bound = x + r > 720 ? 720 : x + r;
  int upper_bound = y + r > 720 ? 720 : y + r;
  int lower_bound = y - r < 0 ? 0 : y - r;

  int r_limit = r * r;
  for (int i = lower_bound; i <= upper_bound; i++) {
    for (int j = left_bound; j <= right_bound; j++) {
      if ((i - y) * (i - y) + (j - x) * (j - x) <= r_limit) {
        fb[i * 720 + j] = erase ? fb_bg[i * 720 + j] : color;
      }
    }
  }
}

void drawCircleHollow(int x, int y, int r, uint16_t color, uint16_t* fb, int thickness, bool erase = false) {
  int left_bound = x - r < 0 ? 0 : x - r;
  int right_bound = x + r > 720 ? 720 : x + r;
  int upper_bound = y + r > 720 ? 720 : y + r;
  int lower_bound = y - r < 0 ? 0 : y - r;

  int r_squared;
  int r_limit = r * r;
  int r_outline_limit = (r - thickness) * (r - thickness);
  for (int i = lower_bound; i <= upper_bound; i++) {
    for (int j = left_bound; j <= right_bound; j++) {
      r_squared = (i - y) * (i - y) + (j - x) * (j - x);
      if (r_squared <= r_limit && r_squared >= r_outline_limit) {
        fb[i * 720 + j] = erase ? fb_bg[i * 720 + j] : color;
      }
    }
  }
}

void drawPlanet(int x, int y, int r, uint16_t color, uint16_t* fb) {
  int left_bound = x - r < 0 ? 0 : x - r;
  int right_bound = x + r > 720 ? 720 : x + r;
  int upper_bound = y + r > 720 ? 720 : y + r;
  int lower_bound = y - r < 0 ? 0 : y - r;
  int thickness = planet_thickness;

  int r_squared;
  int r_limit = r * r;
  int r_outline_limit = (r - thickness) * (r - thickness);
  for (int i = lower_bound; i <= upper_bound; i++) {
    for (int j = left_bound; j <= right_bound; j++) {
      r_squared = (i - y) * (i - y) + (j - x) * (j - x);
      if (r_squared > r_limit) continue;
      if (r_squared >= r_outline_limit) {
        fb[i * 720 + j] = OUTLINE_COLOR;
      } else {
        fb[i * 720 + j] = color;
      }
    }
  }
}

void drawAntisolar(int x, int y, int r, uint16_t* fb) {
  int left_bound = x - r < 0 ? 0 : x - r;
  int right_bound = x + r > 720 ? 720 : x + r;
  int upper_bound = y + r > 720 ? 720 : y + r;
  int lower_bound = y - r < 0 ? 0 : y - r;
  int thickness = planet_thickness;

  int antisolar_inner_limit = antisolar_inner_r * antisolar_inner_r;
  int r_squared;
  int r_limit = r * r;
  int r_outline_limit = (r - thickness) * (r - thickness);
  for (int i = lower_bound; i <= upper_bound; i++) {
    for (int j = left_bound; j <= right_bound; j++) {
      r_squared = (i - y) * (i - y) + (j - x) * (j - x);
      if (r_squared > r_limit) continue;
      if (r_squared >= r_outline_limit) {
        fb[i * 720 + j] = OUTLINE_COLOR;
        continue;
      }
      if (r_squared <= antisolar_inner_limit) {
        fb[i * 720 + j] = SUN_COLOR;
        continue;
      }
      fb[i * 720 + j] = BG_COLOR;
    }
  }
}

void drawSun(int x, int y, uint16_t* fb) {

  int r = SUN_SIZE;

  int left_bound = x - r < 0 ? 0 : x - r;
  int right_bound = x + r > 720 ? 720 : x + r;
  int upper_bound = y + r > 720 ? 720 : y + r;
  int lower_bound = y - r < 0 ? 0 : y - r;

  int r_squared;
  int r_limit = r * r;
  int sun_inner_limit = sun_inner_r * sun_inner_r;
  int sun_ring_limit_outer = sun_ring_r * sun_ring_r;
  int sun_ring_limit_inner = (sun_ring_r - sun_ring_thickness) * (sun_ring_r - sun_ring_thickness);
  for (int i = lower_bound; i <= upper_bound; i++) {
    for (int j = left_bound; j <= right_bound; j++) {
      r_squared = (i - y) * (i - y) + (j - x) * (j - x);
      if (r_squared > r_limit) continue;
      if (r_squared <= sun_inner_limit) {
        fb[i * 720 + j] = BG_COLOR;
        continue;
      }
      if (r_squared >= sun_ring_limit_inner && r_squared <= sun_ring_limit_outer) {
        fb[i * 720 + j] = BG_COLOR;
        continue;
      }
      fb[i * 720 + j] = SUN_COLOR;
    }
  }
}

void drawMoon(int x, int y, int sun_x, int sun_y, float phase_angle, uint16_t* fb) {
  int thickness = moon_ring_thickness;
  int spacing = moon_ring_spacing;
  float normalized_phase_angle = getNormalizedAngle(phase_angle);
  float sun_moon_angle = atan2((sun_y - y), (sun_x - x));
  float k = cos(normalized_phase_angle);
  float r = MOON_SIZE - thickness - spacing;
  Point2D a = { .x = x + r * k * cos(sun_moon_angle), .y = y + r * k * sin(sun_moon_angle) };
  Point2D b = { .x = x + r * cos(sun_moon_angle + PI / 2), .y = y + r * sin(sun_moon_angle + PI / 2) };
  Point2D c = { .x = x + r * cos(sun_moon_angle + 3 * PI / 2), .y = y + r * sin(sun_moon_angle + 3 * PI / 2) };
  Circle2D d = getCircleFromThreePoints(a, b, c);
  bool right_side_phase = (normalized_phase_angle < PI / 2 || normalized_phase_angle > 3 * PI / 2);  //if the moon is less than first quarter or more than third quarter

  int r_outer = MOON_SIZE;
  int left_bound = x - r_outer < 0 ? 0 : x - r_outer;
  int right_bound = x + r_outer > 720 ? 720 : x + r_outer;
  int upper_bound = y + r_outer > 720 ? 720 : y + r_outer;
  int lower_bound = y - r_outer < 0 ? 0 : y - r_outer;
  int r_squared;
  double distance_from_d_center;

  int r_limit = r_outer * r_outer;
  int border_limit = (r + spacing) * (r + spacing);
  int r_inner_limit = r * r;
  int d_limit = d.r * d.r;
  int d_x = d.x;
  int d_y = d.y;
  for (int i = lower_bound; i <= upper_bound; i++) {
    for (int j = left_bound; j <= right_bound; j++) {
      r_squared = (i - y) * (i - y) + (j - x) * (j - x);
      if (r_squared > r_limit) continue;
      if (r_squared >= border_limit) {
        fb[i * 720 + j] = MOON_COLOR;
        continue;
      }
      if (r_squared > r_inner_limit) {
        fb[i * 720 + j] = BG_COLOR;
        continue;
      }
      distance_from_d_center = (i - d_y) * (i - d_y) + (j - d_x) * (j - d_x);
      if (right_side_phase && (distance_from_d_center >= d_limit)) {
        fb[i * 720 + j] = MOON_COLOR;
        continue;
      } else if (!right_side_phase && (distance_from_d_center <= d_limit)) {
        fb[i * 720 + j] = MOON_COLOR;
        continue;
      }
      fb[i * 720 + j] = BG_COLOR;
    }
  }
}

void drawBoundedArc(int x, int y, int r, Circle2D bound, bool inside, uint16_t color, uint16_t* fb, int thickness) {
  int left_bound = x - r < 0 ? 0 : x - r;
  int right_bound = x + r > 720 ? 720 : x + r;
  int upper_bound = y + r > 720 ? 720 : y + r;
  int lower_bound = y - r < 0 ? 0 : y - r;

  int r_squared;
  int r_limit = r * r;
  int r_outline_limit = (r - thickness) * (r - thickness);
  int circle_distance;
  int bound_x = bound.x;
  int bound_y = bound.y;
  int bound_r = bound.r;
  for (int i = lower_bound; i <= upper_bound; i++) {
    for (int j = left_bound; j <= right_bound; j++) {
      circle_distance = (i - bound_y) * (i - bound_y) + (j - bound_x) * (j - bound_x);
      if (inside ^ (circle_distance < bound_r * bound_r)) continue;
      r_squared = (i - y) * (i - y) + (j - x) * (j - x);
      if (r_squared <= r_limit && r_squared >= r_outline_limit) {
        fb[i * 720 + j] = color;
      }
    }
  }
}

RetrogradeInfo getRetrogradeInfo(double jd_a, double jd_b, PlanetData pd_a, PlanetData pd_b) {
  if (jd_a > jd_b) {
    return RetrogradeInfo{
      .mercury_r = isRetrograde(pd_a.mercury_ecl_latlong.lon, pd_b.mercury_ecl_latlong.lon),
      .venus_r = isRetrograde(pd_a.venus_ecl_latlong.lon, pd_b.venus_ecl_latlong.lon),
      .mars_r = isRetrograde(pd_a.mars_ecl_latlong.lon, pd_b.mars_ecl_latlong.lon),
      .jupiter_r = isRetrograde(pd_a.jupiter_ecl_latlong.lon, pd_b.jupiter_ecl_latlong.lon),
      .saturn_r = isRetrograde(pd_a.saturn_ecl_latlong.lon, pd_b.saturn_ecl_latlong.lon)
    };
  }
  else {
    return RetrogradeInfo{
      .mercury_r = isRetrograde(pd_b.mercury_ecl_latlong.lon, pd_a.mercury_ecl_latlong.lon),
      .venus_r = isRetrograde(pd_b.venus_ecl_latlong.lon, pd_a.venus_ecl_latlong.lon),
      .mars_r = isRetrograde(pd_b.mars_ecl_latlong.lon, pd_a.mars_ecl_latlong.lon),
      .jupiter_r = isRetrograde(pd_b.jupiter_ecl_latlong.lon, pd_a.jupiter_ecl_latlong.lon),
      .saturn_r = isRetrograde(pd_b.saturn_ecl_latlong.lon, pd_a.saturn_ecl_latlong.lon)
    };
  }
}

bool isRetrograde(float lon_current, float lon_past) {
  if (lon_current > lon_past + PI) return true;
  return lon_past > lon_current;
}
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
void loop() {
  date_changed = false;
  angle_changed = false;

  if (encoder_irq) {
    encoder_irq = false;
    encoder_return = interface->serviceEncoder();
    if (encoder_return.date_offset != 0) {
      sidereal_day_offset += encoder_return.date_offset;
      time_calculator->setOffset(sidereal_day_offset);
      date_changed = true;
      date_change_eph_request = true;
    }
    if (encoder_return.settings_changed) {
        new_settings = interface->getSettings();
        initializeSettings(new_settings.latitude, new_settings.longitude, new_settings.UTC_offset, new_settings.DST);
        loop_entry_counter = 2;
    }
    if (encoder_return.calibration_changed) {
      setCalibration(interface->getCalibration());
    }
  }

  if (button_irq) {
    button_irq = false;
    interface->serviceButton();
  }

  sum_pot = 0;
  for (i = 0; i < buffer_size; i++) {
    if (i < n_sample) {
      buffer.unshift(analogRead(A0));
      sum_pot += buffer[0];
    } else {
      sum_pot += buffer[i];
    }
  }
  average_pot = (float)sum_pot / buffer_size;
  angle = -(calibrator->getAngle(average_pot));

  if (abs(old_angle - angle) > 0.02 || loop_entry_counter > 0) {
    old_angle = angle;
    frame_change_counter = post_change_frames;
    angle_changed = true;
  } else {
    angle = old_angle;
  }

  if (loop_entry_counter > 0) loop_entry_counter--;

  if (millis() > timer_eph_sample + 50) {
    old_jd_back = jd;
    jd = time_calculator->getJulianDate(angle);
    if (abs(old_eph_angle - angle) > 0.06 || (!angle_changed && angle_changed_eph_old)) {
      angle_changed_eph_old = angle_changed;
      old_data = data;
      old_jd_front = old_jd_back;
      data = getPlanetData(jd);
      old_eph_angle = angle;
      frame_change_counter = post_change_frames;
    } else if (date_change_eph_request) {
      old_data = data;
      old_jd_front = old_jd_back;
      data = getPlanetData(jd);
      frame_change_counter = post_change_frames;
      date_change_eph_request = false;
    }
    ri = getRetrogradeInfo(jd, old_jd_front, data, old_data);
    timer_eph_sample = millis();

    for (i = 0; i < 19; i ++) {
      switch(i) {
        case 0:
          planets_altaz[i] = getAltAz(angle, data.sun_equ_latlong, latitude);
          break;
        case 1:
          planets_altaz[i] = getAltAz(angle, data.moon_equ_latlong, latitude);
          break;
        case 2:
          planets_altaz[i] = getAltAz(angle, data.mercury_equ_latlong, latitude);
          break;
        case 3:
          planets_altaz[i] = getAltAz(angle, data.venus_equ_latlong, latitude);
          break;
        case 4:
          planets_altaz[i] = getAltAz(angle, data.mars_equ_latlong, latitude);
          break;
        case 5:
          planets_altaz[i] = getAltAz(angle, data.jupiter_equ_latlong, latitude);
          break;
        case 6:
          planets_altaz[i] = getAltAz(angle, data.saturn_equ_latlong, latitude);
          break;
        default:
          stars_altaz[i-7] = getAltAz(angle, fixed_star_data[i-7], latitude);
          break;
      }
    }
  }

  if (millis() > timer_interface_update + 501) {
    dt = time_calculator->getDateTime(jd);
    cusps = tympanum->getHouseCusps(angle);
    InterfaceParams p = { .dt = dt, .pd = data, .cusps = cusps, .ri = ri, .planets_altaz = planets_altaz, .stars_altaz = stars_altaz};
    interface->process(p);
    timer_interface_update = millis();
  }

  if (frame_change_counter > 0) {
    frame_change_counter--;
    for (i = 0; i < n_stars; i++) {
      star_long = -star_data[i][0];
      star_r = star_data[i][1];
      star_size = star_data[i][2];
      old_center_x = 360 + cos(erase_angle + star_long) * star_r * scale_factor;
      old_center_y = 360 + sin(erase_angle + star_long) * star_r * scale_factor;
      center_x = 360 + cos(angle + star_long) * star_r * scale_factor;
      center_y = 360 + sin(angle + star_long) * star_r * scale_factor;
      drawCircle(old_center_x, old_center_y, star_size * k_star_size, BG_COLOR, fb, true);
      drawCircle(center_x, center_y, star_size * k_star_size, STAR_COLOR, fb);
    }

    erase_angle = angle;

    for (i = 0; i < n_planets; i++) {
      switch (i) {
        case MOON:
          planet_coords = getStereoCoords(data.moon_equ_latlong.lat, data.moon_equ_latlong.lon);
          planet_long = -planet_coords.theta;
          phase_angle = planet_long - sun_long;
          planet_r = planet_coords.r;
          planet_color = MOON_COLOR;
          planet_size = MOON_SIZE;
          break;
        case SUN:
          planet_coords = getStereoCoords(data.sun_equ_latlong.lat, data.sun_equ_latlong.lon);
          planet_long = -planet_coords.theta;
          sun_long = planet_long;
          planet_r = planet_coords.r;
          planet_color = SUN_COLOR;
          planet_size = SUN_SIZE;
          break;
        case ANTISOLAR:
          planet_coords = getStereoCoords(-(data.sun_equ_latlong.lat), PI + data.sun_equ_latlong.lon);
          planet_long = -planet_coords.theta;
          planet_r = planet_coords.r;
          planet_color = BG_COLOR;
          planet_size = ANTISOLAR_SIZE;
          break;
        case MERCURY:
          planet_coords = getStereoCoords(data.mercury_equ_latlong.lat, data.mercury_equ_latlong.lon);
          planet_long = -planet_coords.theta;
          planet_r = planet_coords.r;
          planet_color = MERCURY_COLOR;
          planet_size = PLANET_SIZE;
          break;
        case VENUS:
          planet_coords = getStereoCoords(data.venus_equ_latlong.lat, data.venus_equ_latlong.lon);
          planet_long = -planet_coords.theta;
          planet_r = planet_coords.r;
          planet_color = VENUS_COLOR;
          planet_size = PLANET_SIZE;
          break;
        case MARS:
          planet_coords = getStereoCoords(data.mars_equ_latlong.lat, data.mars_equ_latlong.lon);
          planet_long = -planet_coords.theta;
          planet_r = planet_coords.r;
          planet_color = MARS_COLOR;
          planet_size = PLANET_SIZE;
          break;
        case JUPITER:
          planet_coords = getStereoCoords(data.jupiter_equ_latlong.lat, data.jupiter_equ_latlong.lon);
          planet_long = -planet_coords.theta;
          planet_r = planet_coords.r;
          planet_color = JUPITER_COLOR;
          planet_size = PLANET_SIZE;
          break;
        case SATURN:
          planet_coords = getStereoCoords(data.saturn_equ_latlong.lat, data.saturn_equ_latlong.lon);
          planet_long = -planet_coords.theta;
          planet_r = planet_coords.r;
          planet_color = SATURN_COLOR;
          planet_size = PLANET_SIZE;
          break;
      }
      old_center_x = planet_erase_locs[i][0];
      old_center_y = planet_erase_locs[i][1];
      center_x = 360 + cos(angle + planet_long) * planet_r * scale_factor;
      center_y = 360 + sin(angle + planet_long) * planet_r * scale_factor;

      drawCircle(old_center_x, old_center_y, planet_size, BG_COLOR, fb, true);
      planet_erase_locs[i] = { center_x, center_y };
      switch (i) {
        case MERCURY:
        case VENUS:
        case MARS:
        case JUPITER:
        case SATURN:
          drawPlanet(center_x, center_y, planet_size, planet_color, fb);
          break;
        case ANTISOLAR:
          drawAntisolar(center_x, center_y, planet_size, fb);
          break;
        case SUN:
          drawSun(center_x, center_y, fb);
          sun_center_x = center_x;
          sun_center_y = center_y;
          break;
        case MOON:
          drawMoon(center_x, center_y, sun_center_x, sun_center_y, phase_angle, fb);
          break;
      }
    }
  }
}

bool draw_to_buffer(esp_lcd_panel_handle_t panel_handle, const esp_lcd_rgb_panel_event_data_t* edata, void* user_ctx) {
  esp_lcd_panel_draw_bitmap(panel_handle, 0, 0, 720, 720, framebuffer);
  return true;
}

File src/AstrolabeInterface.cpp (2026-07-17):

#include "src/AstrolabeInterface.h"

const char* week_names[7] = {"SUN ", "MON ", "TUE ", "WED ", "THU ", "FRI ", "SAT "};
const char* sign_names[12] = {"ARI", "TAU", "GEM", "CAN", "LEO", "VIR", "LIB", "SCO", "SAG", "CAP", "AQU", "PIS"};
const char* sign_names_long[12] = {
    "ARIES      ",
    "TAURUS     ",
    "GEMINI     ",
    "CANCER     ",
    "LEO        ",
    "VIRGO      ",
    "LIBRA      ",
    "SCORPIO    ",
    "SAGITTARIUS",
    "CAPRICORN  ",
    "AQUARIUS   ",
    "PISCES     "
};
const char* sign_descriptions[12] = {
    "       THE RAM      ",
    "      THE BULL      ",
    "      THE TWINS     ",
    "      THE CRAB      ",
    "      THE LION      ",
    "     THE MAIDEN     ",
    "     THE SCALES     ",
    "    THE SCORPION    ",
    "     THE ARCHER     ",
    "    THE SEA-GOAT    ",
    "  THE WATER-BEARER  ",
    "     THE FISHES     "
};

const char* planet_names[7] = {
    "   SUN   ", 
    "  MOON   ", 
    " MERCURY ", 
    "  VENUS  ", 
    "  MARS   ", 
    " JUPITER ", 
    " SATURN  "};

const char* star_names[12] = {
    "       ALGOL",
    "       RIGEL",
    "      CAPELLA",
    "     BETELGEUSE",
    "       SIRIUS",
    "      PROCYON",
    "       DUBHE",
    "       ALKAID",
    "      ARCTURUS",
    "        VEGA",
    "       ALTAIR",
    "        DENEB"
};

const char* star_descriptions[12] = {
    "  THE DEMON'S HEAD",
    " THE HUNTER'S FOOT",
    "    THE SHE-GOAT",
    " THE HUNTER'S HAND",
    "  THE SEARING ONE",
    "   THE LITTLE DOG",
    "  THE BEAR'S HEAD",
    "  THE BEAR'S TAIL",
    "    THE GUARDIAN",
    "  THE DIVING EAGLE",
    " THE SOARING EAGLE",
    "      THE SWAN"
};

const int max_blink_counter = 1;

const float sign_interval = 30.0;

const int buffer_size = 100;

uint8_t lambda_symbol[8] = {0,8,4,4,10,10,17,17};
uint8_t sun_symbol[8] = {14,17,21,17,14,0,0,0};
uint8_t moon_symbol[8] = {12,18,9,5,5,9,18,12};
uint8_t mercury_symbol[8] = {10,4,14,10,14,4,14,4};
uint8_t venus_symbol[8] = {14,10,14,4,14,4,4,0};
uint8_t mars_symbol[8] = {0,7,3,5,12,18,18,12};
uint8_t jupiter_symbol[8] = {8,4,4,4,8,18,31,2};
uint8_t saturn_symbol[8] = {8,30,8,10,13,9,1,2};

AstrolabeInterface::AstrolabeInterface(InterfaceParams p, Adafruit_PCF8574* _pcf, Settings _settings, float _calibration_k) {
    lcd = new Adafruit_LiquidCrystal(LCD_ADDR);
    lcd->begin(20, 4);
    lcd->createChar(LAMBDA_SYMBOL, lambda_symbol);
    lcd->createChar(SUN_SYMBOL, sun_symbol);
    lcd->createChar(MOON_SYMBOL, moon_symbol);
    lcd->createChar(MERCURY_SYMBOL, mercury_symbol);
    lcd->createChar(VENUS_SYMBOL, venus_symbol);
    lcd->createChar(MARS_SYMBOL, mars_symbol);
    lcd->createChar(JUPITER_SYMBOL, jupiter_symbol);
    lcd->createChar(SATURN_SYMBOL, saturn_symbol);

    lcd->clear();
    lcd->setBacklight(HIGH);

    ss = new Adafruit_seesaw();
    ss->begin(SEESAW_ADDR);
    ss->pinMode(SS_SWITCH, INPUT_PULLUP);
    ss->setGPIOInterrupts((uint32_t)1 << SS_SWITCH, 1);
    ss->enableEncoderInterrupt();

    pcf = _pcf;
    settings = _settings;
    old_settings = settings;
    calibration_k = _calibration_k;
    old_calibration_k = calibration_k;

    pcf->pinMode(RIGHT_RED, OUTPUT);
    pcf->digitalWrite(RIGHT_RED, HIGH);
    pcf->pinMode(RIGHT_GREEN, OUTPUT);
    pcf->digitalWrite(RIGHT_GREEN, HIGH);
    pcf->pinMode(RIGHT_BLUE, OUTPUT);
    pcf->digitalWrite(RIGHT_BLUE, HIGH);
    pcf->pinMode(LEFT_RED, OUTPUT);
    pcf->digitalWrite(LEFT_RED, HIGH);
    pcf->pinMode(LEFT_GREEN, OUTPUT);
    pcf->digitalWrite(LEFT_GREEN, HIGH);
    pcf->pinMode(LEFT_BLUE, OUTPUT);
    pcf->digitalWrite(LEFT_BLUE, HIGH);
    pcf->pinMode(LEFT_BUTTON, INPUT);
    pcf->pinMode(RIGHT_BUTTON, INPUT);
    current_led = AIR;
    led_planet = INFO_SUN;
    old_encoder_position = ss->getEncoderPosition();

    state = DATETIME;
    needs_initialize = true;

    blink_clk = false;
    blink_clk_counter = 0;

    led_status_indicated = false;

    this->initializeLoading();

    old_p = p;
}

void AstrolabeInterface::initializeLoading() {
    lcd->setCursor(0,1);
    lcd->print("     LOADING...     ");
}

void AstrolabeInterface::initializeDatetime(InterfaceParams p) {
    lcd->setCursor(5,1);
    lcd->print(p.dt.year);
    lcd->print("/");
    lcd->print(p.dt.month / 10);
    lcd->print(p.dt.month % 10);
    lcd->print("/"); 
    lcd->print(p.dt.day / 10);
    lcd->print(p.dt.day % 10);

    lcd->setCursor(5, 2);
    int week_day = getDayOfWeek(p.dt.year, p.dt.month, p.dt.day);
    lcd->print(week_names[week_day]);
    lcd->print(p.dt.DST ? "*" : " ");
    lcd->print(p.dt.hour / 10);
    lcd->print(p.dt.hour % 10);
    lcd->print(":");
    lcd->print(p.dt.minute / 10);
    lcd->print(p.dt.minute % 10);
    old_p = p;
}
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

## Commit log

2026-07-03 Adding hardware files
    [Astrolabe_BearingCage.STEP, Astrolabe_BearingInner.STEP, Astrolabe_BearingOuter.STEP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]
2026-07-17 Fix DST setting mistake from commit a04ab19d69807190ba81dfda3674cdfbadd4e90e
    [AstrolabeInterface.cpp]
